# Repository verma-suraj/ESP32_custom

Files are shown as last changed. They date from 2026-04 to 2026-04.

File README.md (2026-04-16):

# ESP32 Custom PCB — Team Circuitrix

A custom ESP32 PCB designed in KiCad.

## Repository Structure

```
ESP32_custom/       # KiCad schematic and PCB design files
  ├── *.kicad_sch   # Schematic
  ├── *.kicad_pcb   # PCB layout
  ├── *.kicad_pro   # Project file
  ├── *.kicad_dru   # Design rules
  └── Gerber File/  # Manufacturing files (Gerber + drill)
Bill of Materials/  # BOM in CSV and XLSX formats
demo/               # 3D board view video and PCB renders
```

## Demo

| Top View | Bottom View |
|---|---|
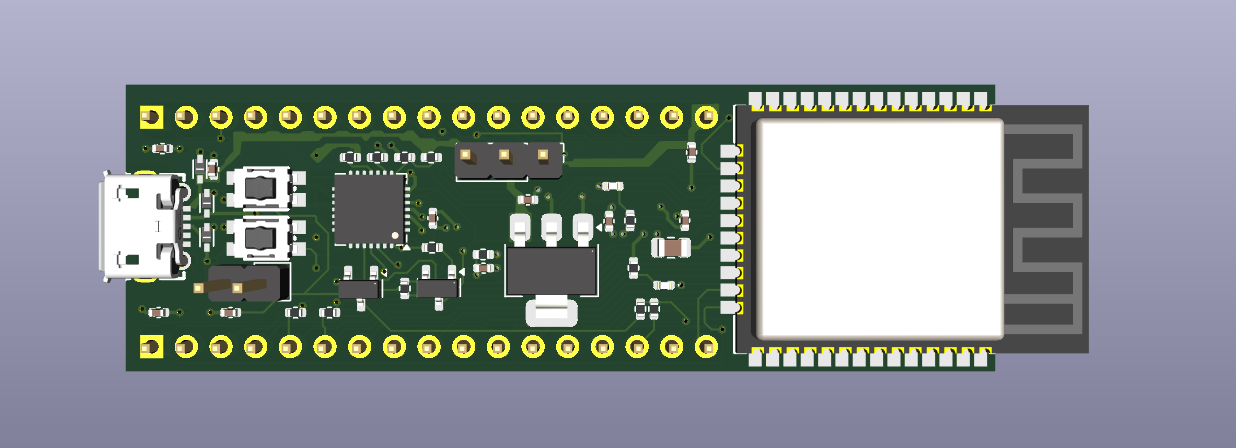
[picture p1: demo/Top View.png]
Top View
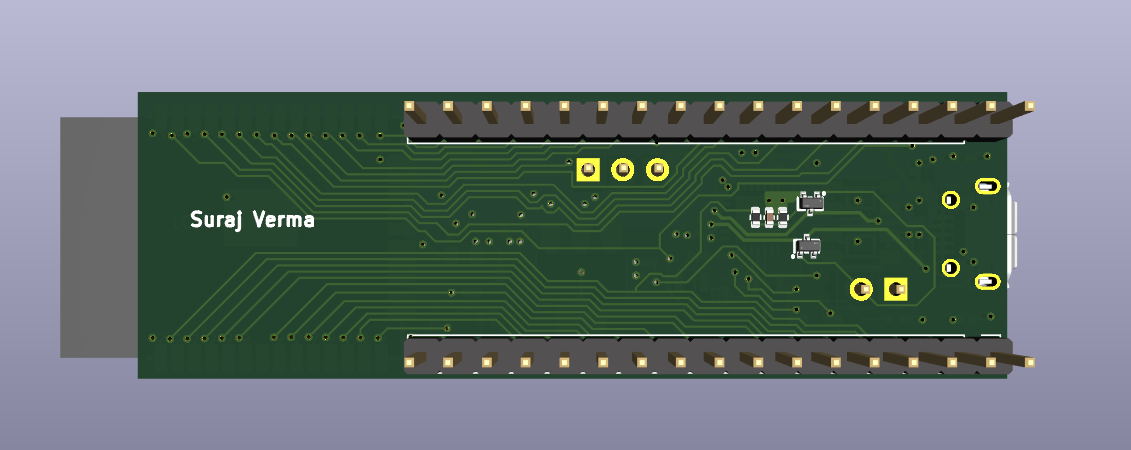
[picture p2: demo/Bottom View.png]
Bottom View
|  |  |

A 3D walkthrough of the board is available in [demo/3D view of the Board.mp4](demo/3D%20view%20of%20the%20Board.mp4).

## Reference Datasheets

- [ESP32-WROOM-32E Datasheet](https://www.espressif.com/sites/default/files/documentation/esp32-wroom-32e_esp32-wroom-32ue_datasheet_en.pdf)
- [ESP32-S2-DevKitM-1 Schematic](https://dl.espressif.com/dl/schematics/ESP32-S2-DevKitM-1_V1_Schematics.pdf)
- [ESP32-DevKitC V4 Schematic](https://dl.espressif.com/dl/schematics/esp32_devkitc_v4-sch.pdf)

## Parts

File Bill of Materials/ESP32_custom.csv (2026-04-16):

Id | Designator | Footprint | Quantity | Designation | Supplier and ref
1 | R14,R15 | R_0402_1005Metric | 2 | R
2 | U2 | QFN-28-1EP_5x5mm_P0.5mm_EP3.35x3.35mm | 1 | CP2102N-Axx-xQFN28
3 | C12,C3,C9,C8,C7,C13,C11,C4 | C_0402_1005Metric | 8 | 100nF
4 | C1 | C_0402_1005Metric | 1 | 10uF
5 | R3 | R_0402_1005Metric | 1 | 5.1K
6 | SW1,SW2 | KEY-SMD_4P-L4.2-W2.8-P1.60-LS4.6 | 2 | KMR621NGLFS
7 | Q3,Q4 | SOT-23 | 2 | SS8050
8 | USB1 | MICRO-USB-SMD_105017-0001 | 1 | 105017-0001
9 | R8,R2 | R_0402_1005Metric | 2 | 1K
10 | C2 | C_0402_1005Metric | 1 | 22uF
11 | R13,R12,R11,R7,R1 | R_0402_1005Metric | 5 | 10K
12 | U3 | WIFI-SMD_ESP32-WROOM-32E | 1 | ESP32-WROOM-32E(4MB)
13 | U1 | SOT-223-3_TabPin2 | 1 | AMS1117-3.3
14 | D1,D2,D3 | SOD-523_L1.2-W0.8-LS1.6-BI | 3 | LESD5D5.0CT1G
15 | R4 | R_0402_1005Metric | 1 | 560
16 | R5 | R_0402_1005Metric | 1 | 22.1K
17 | J2 | PinHeader_1x02_P2.54mm_Vertical | 1 | Conn_01x02_Pin
18 | D4 | LED_0402_1005Metric | 1 | LED1
19 | D5 | LED_0402_1005Metric | 1 | LED2
20 | R9,R10 | R_0402_1005Metric | 2 | 0
21 | C10 | C_0805_2012Metric | 1 | 22uF
22 | J1 | PinHeader_1x03_P2.54mm_Vertical | 1 | Conn_01x03_Pin
23 | C6 | C_0402_1005Metric | 1 | 4.7uF
24 | R6 | R_0402_1005Metric | 1 | 47.5K
25 | Q2,Q1 | SOT-523-3_L1.6-W0.8-P1.00-LS1.6-BR | 2 | 2N7002T-7-F
26 | J3,J4 | PinHeader_1x17_P2.54mm_Vertical | 2 | Conn_01x17_Pin

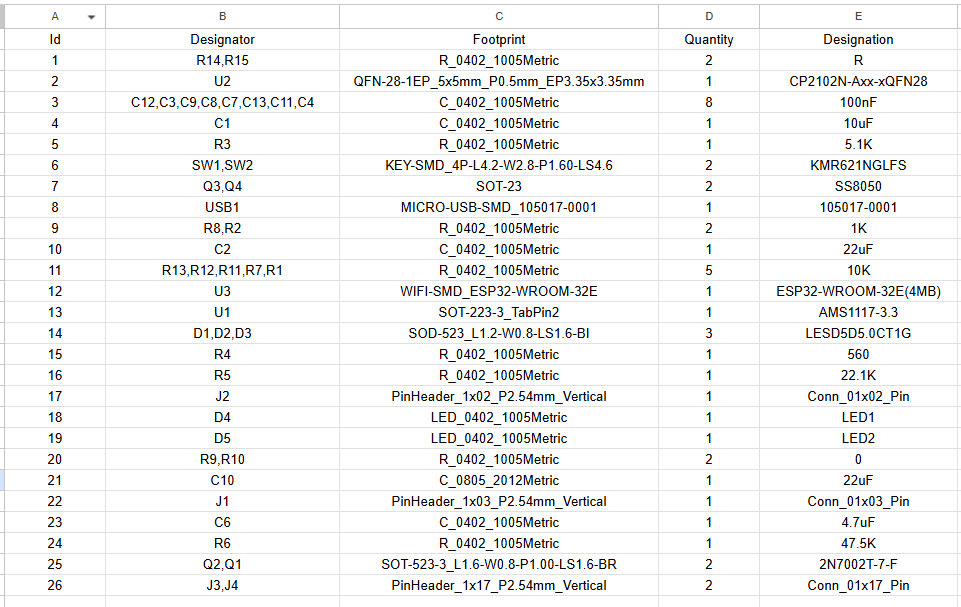
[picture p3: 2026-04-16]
Bill of Materials/BOM.png

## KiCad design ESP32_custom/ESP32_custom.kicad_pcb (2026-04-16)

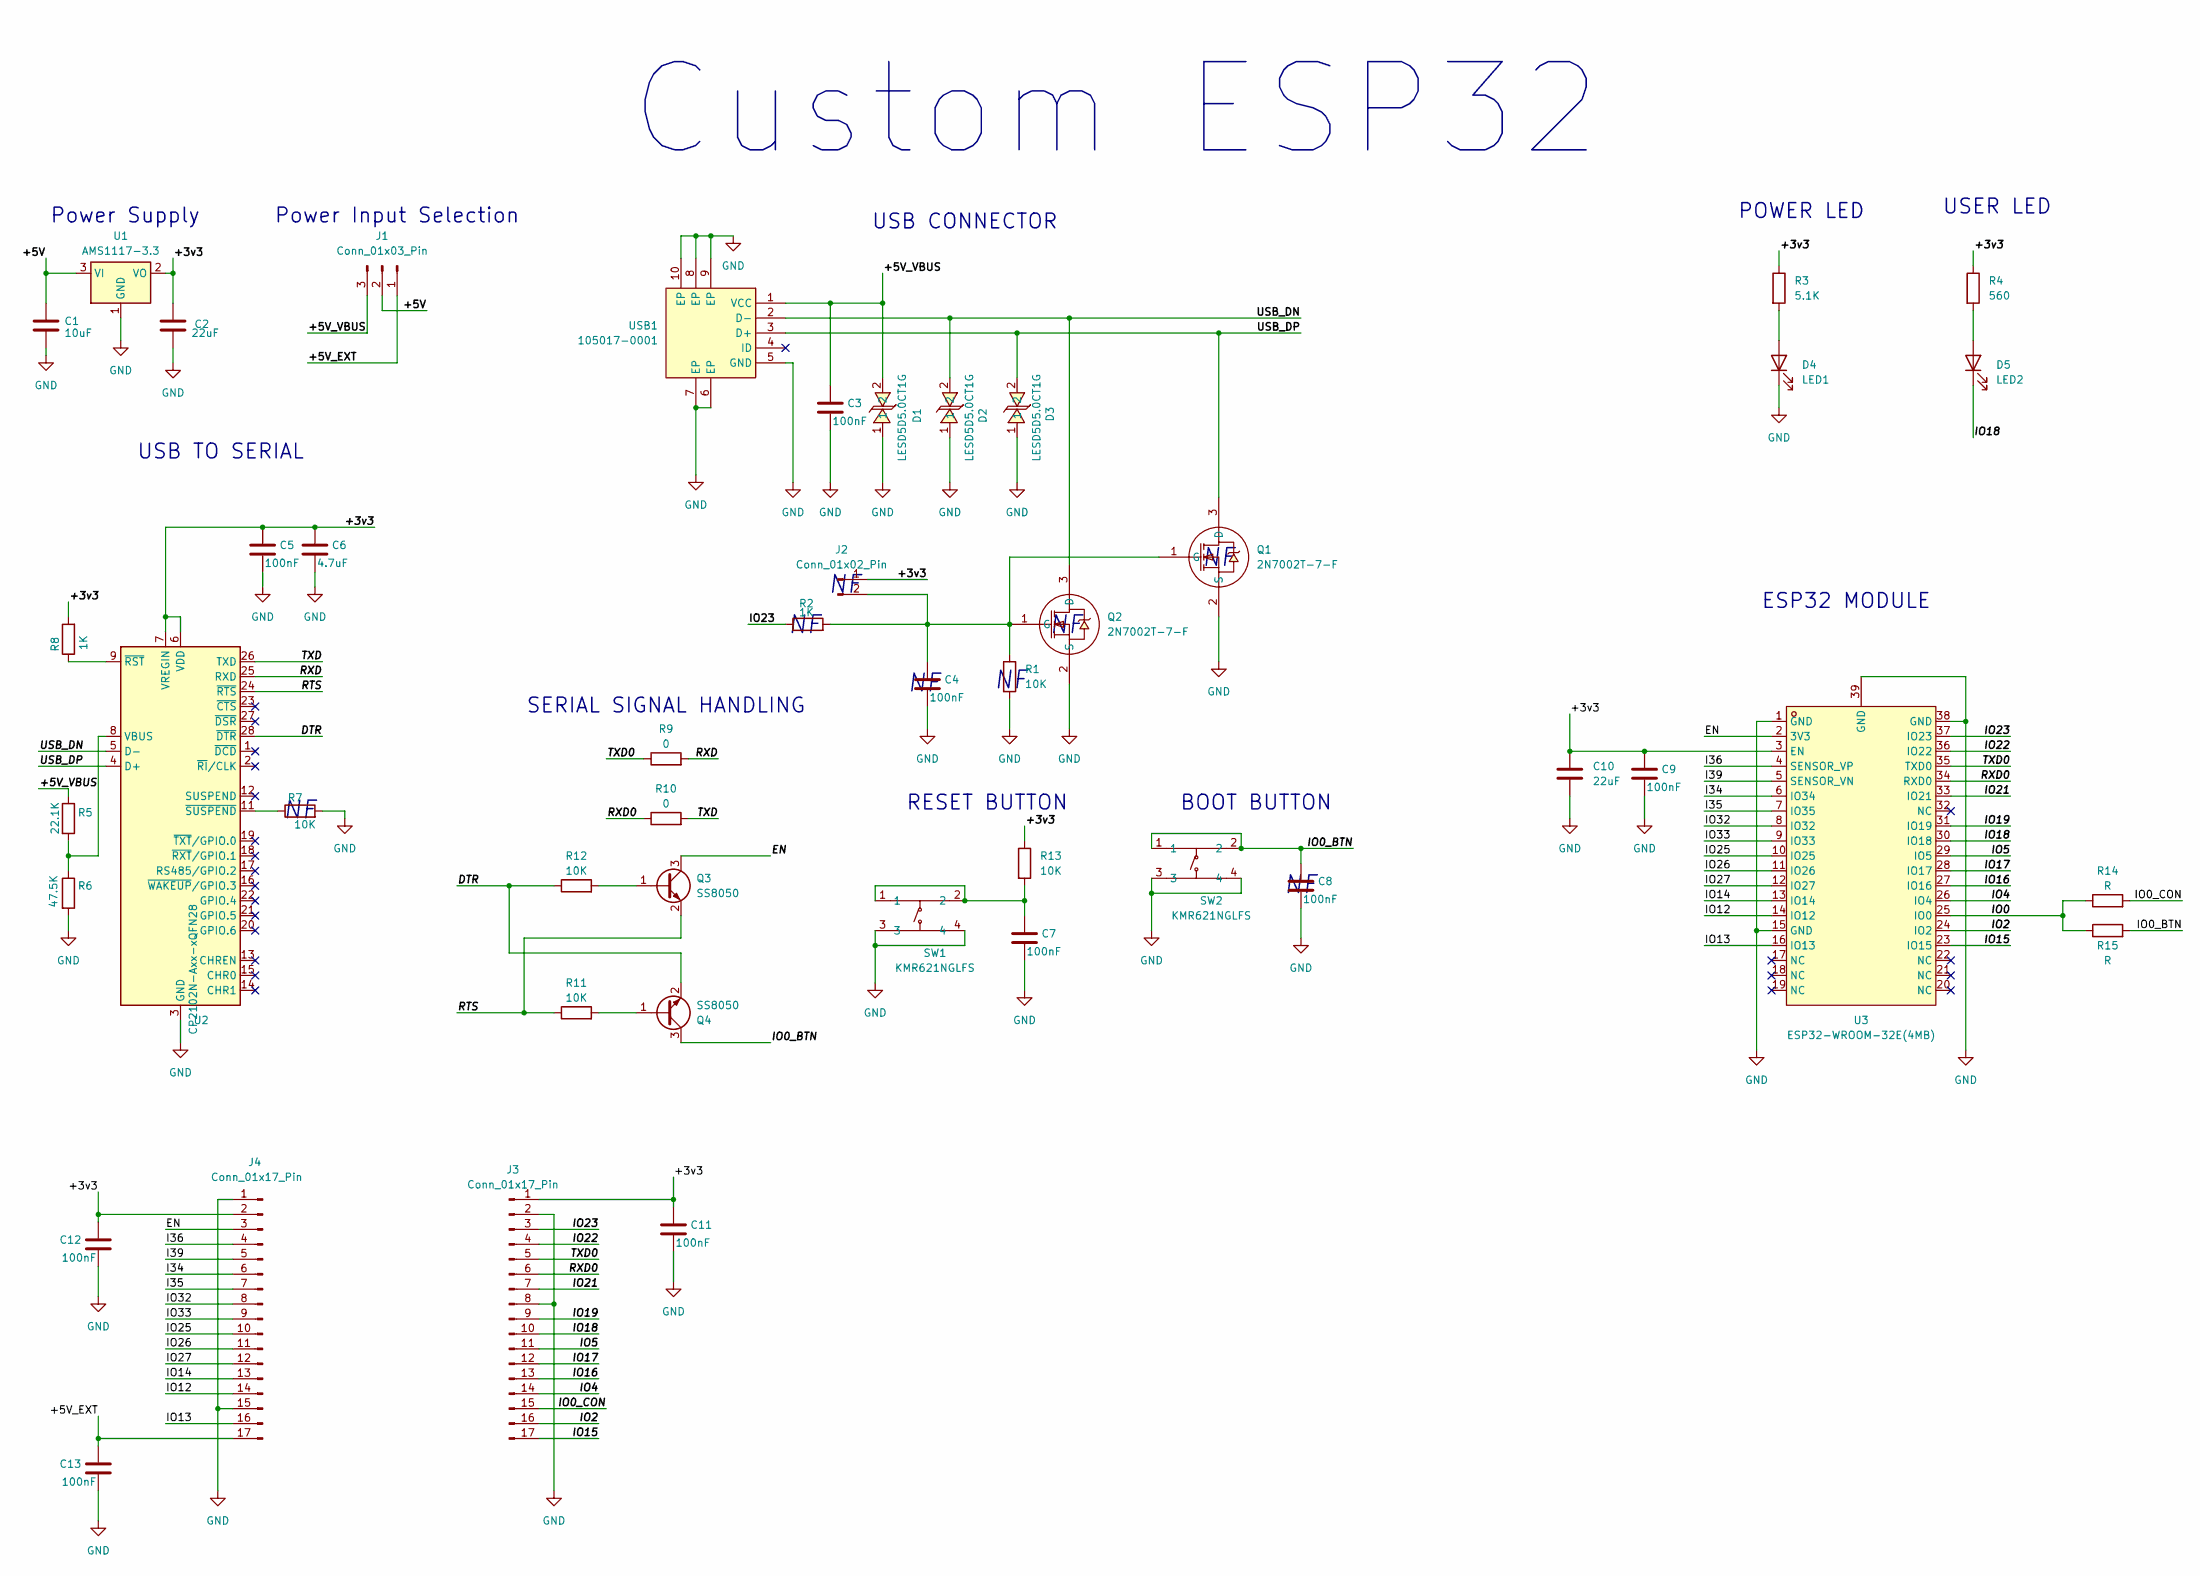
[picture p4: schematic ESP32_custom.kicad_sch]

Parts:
C1: 10uF; C_0402_1005Metric
C2: 22uF; C_0402_1005Metric
C3, C4, C5, C7, C8, C9, C11, C12, C13: 100nF; C_0402_1005Metric
C6: 4.7uF; C_0402_1005Metric
C10: 22uF; C_0805_2012Metric
D1, D2, D3: LESD5D5.0CT1G; SOD-523_L1.2-W0.8-LS1.6-BI; LCSC Part C5199850
D4: LED1; LED_0402_1005Metric
D5: LED2; LED_0402_1005Metric
J1: Conn_01x03_Pin; PinHeader_1x03_P2.54mm_Vertical
J2: Conn_01x02_Pin; PinHeader_1x02_P2.54mm_Vertical
J3, J4: Conn_01x17_Pin; PinHeader_1x17_P2.54mm_Vertical
Q1, Q2: 2N7002T-7-F; SOT-523-3_L1.6-W0.8-P1.00-LS1.6-BR; LCSC Part C139445
Q3, Q4: SS8050; SOT-23
R1, R7, R11, R12, R13: 10K; R_0402_1005Metric
R2, R8: 1K; R_0402_1005Metric
R3: 5.1K; R_0402_1005Metric
R4: 560; R_0402_1005Metric
R5: 22.1K; R_0402_1005Metric
R6: 47.5K; R_0402_1005Metric
R9, R10: 0; R_0402_1005Metric
R14, R15: R; R_0402_1005Metric
SW1, SW2: KMR621NGLFS; KEY-SMD_4P-L4.2-W2.8-P1.60-LS4.6; LCSC Part C221692
U1: AMS1117-3.3; SOT-223-3_TabPin2
U2: CP2102N-Axx-xQFN28; QFN-28-1EP_5x5mm_P0.5mm_EP3.35x3.35mm
U3: ESP32-WROOM-32E(4MB); WIFI-SMD_ESP32-WROOM-32E; LCSC Part C701341
USB1: 105017-0001; MICRO-USB-SMD_105017-0001; LCSC Part C136000

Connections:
/+3v3: C2.1, C5.1, C6.1, C9.1, C10.1, C11.1, C12.1, J2.1, J3.1, J4.2, R3.1, R4.1, R8.2, R13.1, U1.2 (VO), U2.6 (VDD), U2.7 (VREGIN), U3.3 (EN)
/+5V: C1.1, J1.2, U1.3 (VI)
/+5V_EXT: C13.1, J1.1, J4.17
/+5V_VBUS: C3.1, D1.2, J1.3, R5.1, USB1.1 (VCC)
/DTR: Q4.2 (E), R12.1, U2.28 (~DTR)
/EN: J4.3, Q3.3 (C), U3.2 (3V3)
/I34: J4.6, U3.6 (IO34)
/I35: J4.7, U3.7 (IO35)
/I36: J4.4, U3.4 (SENSOR_VP)
/I39: J4.5, U3.5 (SENSOR_VN)
/IO0: R14.1, R15.1, U3.25 (IO0)
/IO0_BTN: C8.1, Q4.3 (C), R15.2, SW2.1, SW2.2
/IO0_CON: J3.15, R14.2
/IO2: J3.16, U3.24 (IO2)
/IO4: J3.14, U3.26 (IO4)
/IO5: J3.11, U3.29 (IO5)
/IO12: J4.14, U3.14 (IO12)
/IO13: J4.16, U3.16 (IO13)
/IO14: J4.13, U3.13 (IO14)
/IO15: J3.17, U3.23 (IO15)
/IO16: J3.13, U3.27 (IO16)
/IO17: J3.12, U3.28 (IO17)
/IO18: D5.1 (K), J3.10, U3.30 (IO18)
/IO19: J3.9, U3.31 (IO19)
/IO21: J3.7, U3.33 (IO21)
/IO22: J3.4, U3.36 (IO22)
/IO23: J3.3, R2.1, U3.37 (IO23)
/IO25: J4.10, U3.10 (IO25)
/IO26: J4.11, U3.11 (IO26)
/IO27: J4.12, U3.12 (IO27)
/IO32: J4.8, U3.8 (IO32)
/IO33: J4.9, U3.9 (IO33)
/RTS: Q3.2 (E), R11.1, U2.24 (~RTS)
/RXD: R9.2, U2.25 (RXD)
/RXD0: J3.6, R10.1, U3.34 (RXD0)
/TXD: R10.2, U2.26 (TXD)
/TXD0: J3.5, R9.1, U3.35 (TXD0)
/USB_DN: D2.2, Q2.3 (D), U2.5 (D-), USB1.2 (D-)
/USB_DP: D3.2, Q1.3 (D), U2.4 (D+), USB1.3 (D+)
GND: C1.2, C2.2, C3.2, C4.2, C5.2, C6.2, C7.2, C8.2, C9.2, C10.2, C11.2, C12.2, C13.2, D1.1, D2.1, D3.1, D4.1 (K), J3.2, J3.8, J4.1, J4.15, Q1.2 (S), Q2.2 (S), R1.2, R6.2, R7.2, SW1.3, SW1.4, SW2.3, SW2.4, U1.1 (GND), U2.3 (GND), U2.29 (GND), U3.1 (GND), U3.15 (GND), U3.38 (GND), U3.39 (GND), USB1.5 (GND), USB1.6 (EP), USB1.7 (EP), USB1.8 (EP), USB1.9 (EP), USB1.10 (EP)
unnamed: C7.1, R13.2, SW1.1, SW1.2
unnamed: D4.2 (A), R3.2
unnamed: D5.2 (A), R4.2
unnamed: C4.1, J2.2, Q1.1 (G), Q2.1 (G), R1.1, R2.2
unnamed: Q3.1 (B), R12.2
unnamed: Q4.1 (B), R11.2
unnamed: R5.2, R6.1, U2.8 (VBUS)
unnamed: R8.1, U2.9 (~RST)
unnamed: R7.1, U2.11 (~SUSPEND)

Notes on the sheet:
Power Supply
ESP32 MODULE
Custom ESP32
BOOT BUTTON
USB CONNECTOR
SERIAL SIGNAL HANDLING
POWER LED
RESET BUTTON
USER LED
Power Input Selection
USB TO SERIAL

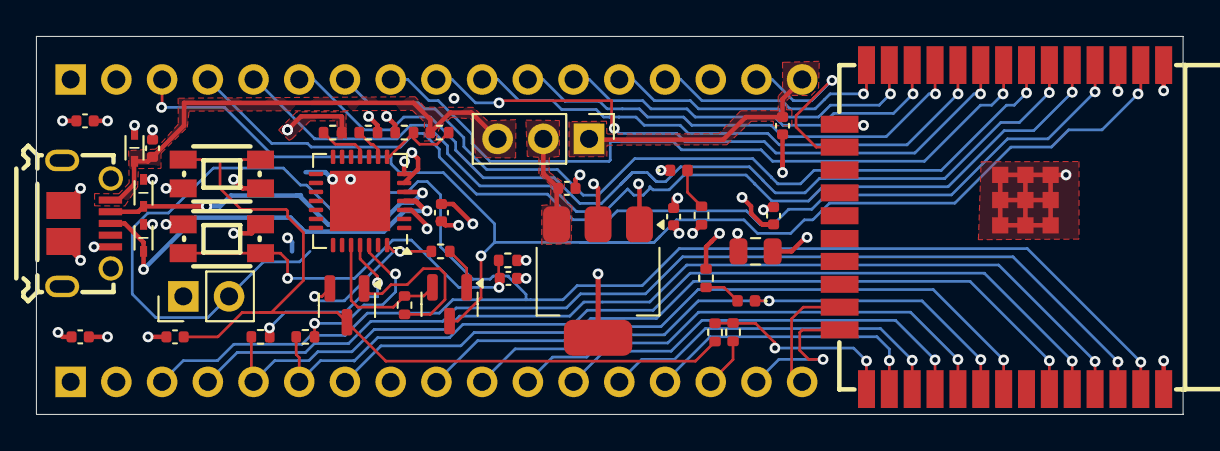
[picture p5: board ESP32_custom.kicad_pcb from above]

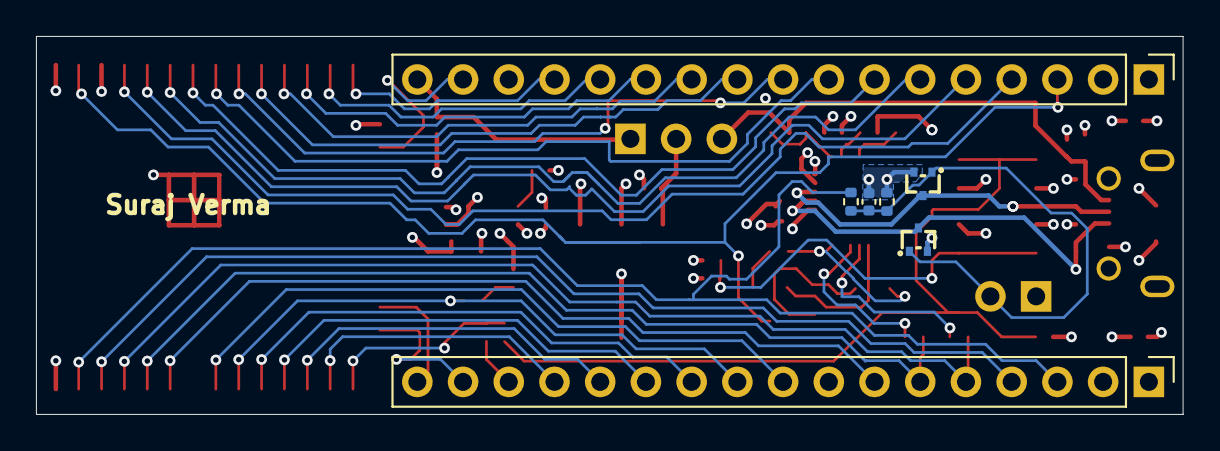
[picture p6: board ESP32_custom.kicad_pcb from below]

Board: 4 copper layers, 63.7 x 21.0 mm, 46 parts (7 on the bottom side), 49 nets.

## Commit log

2026-04-16 Initial commit: ESP32 custom PCB design (KiCad)
    Includes schematic, PCB layout, Gerber files, and BOM.
    Reference datasheets linked in README instead of stored in repo.
    [ESP32_custom-B_Adhesive.gbr, ESP32_custom-B_Cu.gbr, ESP32_custom-B_Mask.gbr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]
2026-04-16 Add demo folder with 3D board view and PCB renders
2026-04-16 Update README with demo section and board renders
